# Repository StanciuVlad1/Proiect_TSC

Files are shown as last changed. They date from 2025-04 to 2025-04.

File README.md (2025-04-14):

## Stanciu Vlad-Mihai
#### 331CC
<br><br>

OpenBook este un proiect open-source care urmărește să aducă lectura digitală mai aproape de oricine, printr-un dispozitiv accesibil și ușor de reprodus. În cadrul acestui start-up, dezvoltăm un eBook Reader minimalist, construit pe platforma ESP32-C6, echipat cu un ecran e-paper de 7.5 inch, baterie Li-Po, încărcare prin USB-C și butoane fizice pentru navigare.

Dispozitivul este conceput să fie eficient din punct de vedere energetic și intuitiv în utilizare, oferind o interfață simplă bazată pe GPIO, optimizată pentru afișarea de texte și o experiență de e-reading plăcută.

## Cuprins

- [Prezentare Proiect](#prezentare-proiect)
- [Diagramă Bloc](#diagrama-bloc)
- [Lista de Materiale (BOM)](#lista-de-materiale-bom)
- [Funcționalitate Hardware](#functionalitate-hardware)
- [Alocarea Pinilor ESP32-C6](#alocarea-pinilor-esp32-c6)
- [Note de Design](#note-de-design)

## Prezentare Proiect

OpenBook este un cititor de e-bookuri open-source bazat pe microcontrolerul ESP32-C6. Dispozitivul include un display e-paper, stocare pe card SD pentru e-bookuri, o interfață USB-C pentru alimentare și date, și un design compact care se potrivește într-o carcasă personalizată. Scopul este crearea unui e-reader ieftin, modificabil, care poate fi produs în masă, respectând principiile open-source.

Acest repository conține:

- **Hardware**: Fișiere pentru schemă electrică și PCB.
- **Manufacturing**: Fișiere Gerber, Lista de Materiale (BOM) și fișiere Pick and Place.
- **Mechanical**: Modele 3D ale dispozitivului complet (PCB, baterie, display și carcasă).
- **Images**: Randări ale PCB-ului și dispozitivului.

## 🗂️ Diagrama bloc



## Lista de Materiale (BOM)

Tabelul următor listează componentele folosite în designul OpenBook, cu link-uri către furnizori și datasheet-uri.

| Componentă | Număr Piesă | Cantitate | Link Furnizor | Link Datasheet | Note |
|---|---|---|---|---|---|
| Senzor mediu | BME680 | 1 | [SnapEDA](https://www.snapeda.com/parts/BME680/Bosch/view-part/?welcome=home) | [Bosch](https://www.bosch-sensortec.com/media/boschsensortec/downloads/datasheets/bst-bme680-ds001.pdf) | Senzor temperatură, umiditate |
| Buton tactil | EVQPUJ02K | 3 | [Panasonic](https://industry.panasonic.com/global/en/products/control/switch/light-touch/number/evqpuj02k) | [LCSC](https://www.lcsc.com/datasheet/lcsc_datasheet_2201121800_PANASONIC-EVQPUJ02K_C2936858.pdf) | Butoane navigare și pornire |
| Condensator | R0402 100K | [TBD] | [ComponentSearch](https://componentsearchengine.com/part-view/R0402%201%25%20100%20K%20(RC0402FR-07100KL)/YAGEO) | [Resistor](https://www.resistor.com/assets/pdf/0402tstd.pdf) | Condensator decuplare, SMD 0402 |
| Rezistor | R0402 100K | [TBD] | [ComponentSearch](https://componentsearchengine.com/part-view/R0402%201%25%20100%20K%20(RC0402FR-07100KL)/YAGEO) | [Resistor](https://www.resistor.com/assets/pdf/0402tstd.pdf) | Rezistor, SMD 0402 |
| Baterie | CPH3225A | 1 | [SnapEDA](https://www.snapeda.com/parts/CPH3225A/Seiko+Instruments/view-part/?ref=eda) | [Octopart](https://octopart.com/datasheet/cph3225a-seiko-25340571) | Baterie Li-Po, ~500mAh |
| LED | KP-1608SURCK | 1 | [SnapEDA](https://www.snapeda.com/parts/KP-1608SURCK/Kingbright/view-part/?ref=search&t=LED%200603) | [ELV](https://media.elv.com/file/107153_led_surck1608_data.pdf) | LED 0603, indicator |
| Protecție ESD | USBLC6-2SC6Y | 1 | [SnapEDA](https://www.snapeda.com/parts/USBLC6-2SC6Y/STMicroelectronics/view-part/?ref=eda) | [DigiKey](https://www.digikey.com/en/htmldatasheets/production/1375342/0/0/1/usblc6-2sc6y) | Protecție USB |
| Diodă Schottky | SD0805S020S1R0 | 1 | [Mouser](https://ro.mouser.com/ProductDetail/KYOCERA-AVX/SD0805S020S1R0?qs=jCA%252BPfw4LHbpkAoSnwrdjw%3D%3D) | [AllDataSheet](https://www.alldatasheet.com/view.jsp?Searchword=SD0805S&sField=2) | Diodă pentru alimentare |
| Supresor ESD | PGB1010603MR | 1 | [SnapEDA](https://www.snapeda.com/parts/PGB1010603MR/Littelfuse/view-part/?ref=eda) | [AllDataSheet](https://www.alldatasheet.com/view.jsp?Searchword=Pgb1010603mr) | Protecție ESD |
| Detector tensiune | BD5229G-TR | 1 | [ComponentSearch](https://componentsearchengine.com/part-view/BD5229G-TR/ROHM%20Semiconductor) | [LCSC](https://www.lcsc.com/datasheet/lcsc_datasheet_2201131330_ROHM-Semicon-BD5229G-TR_C962636.pdf) | Monitorizare tensiune |
| Regulator tensiune | XC6220A331MR-G | 1 | [ComponentSearch](https://componentsearchengine.com/part-view/XC6220A331MR-G/Torex) | [AllDataSheet](https://www.alldatasheet.com/view.jsp?Searchword=Xc6220) | Regulator 3.3V |
| Conector USB-C | USB4110-GF-A | 1 | [ComponentSearch](https://componentsearchengine.com/part-view/USB4110-GF-A/GCT%20(GLOBAL%20CONNECTOR%20TECHNOLOGY)) | [GCT](https://gct.co/files/drawings/usb4110.pdf) | Interfață USB-C |
| LED | LEDCHIP-LED0603 | 1 | [Mouser](https://eu.mouser.com/ProductDetail/Adafruit/4208?qs=PzGy0jfpSMtbScLbr0L5dw%3D%3D) | [Arrow](https://www.arrow.com/en/manufacturers/adafruit-industries/datasheets) | LED 0603, Adafruit |
| Bobină | [TBD] | 1 | [Comet](https://store.comet.srl.ro/Catalogue/Product/43497/) | [Scribd](https://www.scribd.com/document/814581278/Datasheet-Bobina) | Inductor pentru alimentare |
| Siguranță resetabilă | PFMF | 1 | [Mouser](https://www.mouser.co.uk/ProductDetail/EPCOS-TDK/B72520T0350K062?qs=dEfas%2FXlABIszF52uu7vrg%3D%3D) | [Mouser](https://ro.mouser.com/c/ds/circuit-protection/thermistors/resettable-fuses-pptc/?m=Schurter&series=PFMF) | Protecție circuit |
| MOSFET | DMG2305UX-7 | 1 | [ComponentSearch](https://componentsearchengine.com/part-view/DMG2305UX-7/Diodes%20Incorporated) | [Mouser](https://www.mouser.com/datasheet/2/115/DMG2305UX-266242.pdf) | Comutare putere |
| MOSFET | Si1308EDL-T1-GE3 | 1 | [ComponentSearch](https://componentsearchengine.com/part-view/SI1308EDL-T1-GE3/Vishay) | [AllDataSheet](https://www.alldatasheet.com/view.jsp?Searchword=Si1308edl) | Comutare putere |
| IC management baterie | MCP73831T-5ACI/OT | 1 | [Mouser](https://www.mouser.co.uk/ProductDetail/Microchip-Technology/MCP73831T-5ACI-OT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) | [Microchip](https://ww1.microchip.com/downloads/en/DeviceDoc/MCP73831-Family-Data-Sheet-DS20001984H.pdf) | Încărcare baterie |
| Lipire SMD | SMD Solder | [TBD] | [GrabCAD](https://grabcad.com/library/solder-jumpers-1) | - | Pentru asamblare SMD |
| Memorie flash | W25Q512JVEIQ | 1 | [SnapEDA](https://www.snapeda.com/parts/W25Q512JVEIQ/Winbond+Electronics/view-part/) | [Mouser](https://www.mouser.com/datasheet/2/949/W25Q512JV_SPI_RevB_06252019_KMS-2487502.pdf) | Memorie SPI |
| Modul microcontroler | ESP32-C6-WROOM-1-N8 | 1 | [SnapEDA](https://www.snapeda.com/parts/ESP32-C6-WROOM-1-N8/Espressif+Systems/view-part/?ref=eda) | [Mouser](https://www.mouser.com/catalog/specsheets/Espressif_ESP32_C6_WROOM_1%20_Datasheet_V0.1_PRELIMINARY_en.pdf) | Modul Wi-Fi/Bluetooth |
| Ceas timp real | DS3231SN# | 1 | [SnapEDA](https://www.snapeda.com/parts/DS3231SN%23/Analog+Devices/view-part/?ref=eda) | [AllDataSheet](https://www.alldatasheet.com/view.jsp?Searchword=Ds3231sn%20datasheet) | RTC pentru timp |
| Monitor baterie | MAX17048G+T10 | 1 | [SnapEDA](https://www.snapeda.com/parts/MAX17048G+T10/Analog+Devices/view-part/?ref=eda) | [AllDataSheet](https://www.alldatasheet.com/view.jsp?Searchword=Max17048) | Monitorizare nivel baterie |

## Funcționalitate Hardware

Hardware-ul OpenBook este proiectat pentru a echilibra costul, eficiența energetică și funcționalitatea. Caracteristicile principale includ:

- **Microcontroler ESP32-C6**:
  - **Nucleu**: Procesor RISC-V single-core.
  - **Conectivitate**: Wi-Fi 6 și Bluetooth 5 pentru actualizări de firmware sau integrare cloud.
  - **Interfețe**: SPI pentru display și card SD, GPIO pentru butoane, USB pentru alimentare și depanare.
  - **Consum de energie**: Optimizat pentru funcționare cu consum redus, cu moduri de sleep pentru a prelungi durata bateriei.

- **Display E-Paper**:
  - Display e-paper de 2.13" (rezoluție [TBD, ex. 250x122 pixeli]).
  - Conectat prin SPI pentru actualizare rapidă și consum redus.
  - Ideal pentru citit în diverse condiții de iluminare, cu consum minim.

- **Modul Card SD**:
  - Stochează e-bookuri și alte fișiere media.
  - Conectat prin SPI pentru transfer de date fiabil.
  - Suportă carduri microSD standard.

- **Interfață USB-C**:
  - Furnizează alimentare (intrare 5V) și încarcă bateria prin IC-ul de management al puterii.
  - Suportă transfer de date pentru depanare sau actualizări de firmware.

- **Baterie și Management Putere**:
  - Baterie Li-Po de 3.7V (~500mAh, capacitate exactă [TBD]).
  - IC de management al puterii (ex. TP4056) gestionează încărcarea și reglarea tensiunii (3.3V pentru ESP32 și alte componente).
  - Durata estimată a bateriei: [TBD, ex. 20 ore de citire activă], bazată pe calcule pentru actualizarea display-ului, modurile sleep ale ESP32 și accesul la cardul SD.

- **Butoane**:
  - Trei butoane tactile pentru navigare (următoarea/pagina anterioară) și pornire/meniu.
  - Conectate la pinii GPIO ai ESP32 cu rezistoare pull-up.

- **Calcule Consum Energie**:
  - ESP32-C6 (activ): ~100mA la 3.3V.
  - Display E-Paper (actualizare): ~10mA pentru 1s per pagină.
  - Card SD (citire): ~50mA în timpul accesului.
  - Consum total activ: [TBD, ex. ~150mA mediu].
  - Mod sleep: [TBD, ex. <1mA].

*(Notă: Actualizează consumul de energie și alte specificații pe baza alegerilor tale de design și a datasheet-urilor.)*

## Alocarea Pinilor ESP32-C6

Pinii ESP32-C6 sunt alocați astfel:

| Pin | Funcție | Componentă/Modul | Note |
|---|---|---|---|
| GPIO0 | SPI MOSI | Display E-Paper, Card SD| Bus SPI comun |
| GPIO1 | SPI MISO | Display E-Paper, Card SD| Bus SPI comun |
| GPIO2 | SPI SCK | Display E-Paper, Card SD| Bus SPI comun |
| GPIO3 | SPI CS (Display) | Display E-Paper | Selectare cip pentru display |
| GPIO4 | SPI CS (Card SD) | Modul Card SD | Selectare cip pentru card SD |
| GPIO5 | Buton 1 (Pagina Urm.) | Buton Tactil | Pull-up, activ low |
| GPIO6 | Buton 2 (Pagina Ant.) | Buton Tactil | Pull-up, activ low |
| GPIO7 | Buton 3 (Pornire/Meniu) | Buton Tactil | Pull-up, activ low |
| GPIO8 | Reset Display | Display E-Paper | Activ low |
| GPIO9 | Busy Display | Display E-Paper | Intrare de la display |
| VBUS | Alimentare USB | Conector USB-C | Intrare 5V |
| 3V3 | Linie Alimentare | Toate componentele | Reglat din baterie/USB |

*(Notă: Verifică alocarea pinilor față de schemă. Actualizează tabelul cu numerele exacte ale pinilor și funcțiile pe baza designului tău.)*

### De ce acești pini?

- **Pini SPI (GPIO0-4)**: Aleși pentru suportul hardware dedicat SPI, asigurând comunicație rapidă și fiabilă cu display-ul și cardul SD. Un bus SPI comun minimizează utilizarea pinilor.
- **Pini Butoane (GPIO5-7)**: Selectați pentru capabilitățile de intrare generală și suport pentru întreruperi, permițând interacțiune rapidă cu utilizatorul.
- **Pini Control Display (GPIO8-9)**: Folosiți pentru semnalele de reset și busy, conform cerințelor datasheet-ului display-ului e-paper.
- **Pini Alimentare (VBUS, 3V3)**: Standard pentru livrarea și reglarea energiei.

## Note de Design

- **Schemă și Design PCB**:
  - Schema (`Hardware/openbook.sch`) respectă referința furnizată.
  - Layout-ul PCB (`Hardware/openbook.brd`) respectă constrângerile mecanice, cu toate componentele pe stratul TOP și rutarea pe ambele straturi TOP și BOTTOM.
  - Traseele de alimentare folosesc lățimea de 0.3mm, iar traseele de semnal au lățimea minimă de 0.15mm, conform ghidului.
  - Antena ESP32-C6 este poziționată la marginea PCB-ului, cu o decupare dedesubt pentru a minimiza interferențele.

- **Design Mecanic**:
  - Modelul 3D (`Mechanical/openbook.step`) include PCB-ul, bateria, display-ul e-paper și carcasa modificată.
  - Bateria se conectează direct la pad-uri de test (fără conector JST) pentru a economisi spațiu.

## 🔧 Provocări și decizii tehnice

- **Erori DRC**  
  Au fost ignorate erorile de tip *"Only INPUT pins on NET ID"* și cele legate de dimensiunile butoanelor și conectorului USB, în conformitate cu ghidul de proiectare, deoarece nu afectează funcționarea corectă a dispozitivului.

- **Amplasarea componentelor**  
  Componentele au fost plasate strategic în jurul ESP32 și al driverului e-paper pentru a reduce lungimea traseelor și a asigura o bună integritate a semnalului.

- **Via Stitching**  
  A fost implementat între planele de masă TOP și BOTTOM, în special în proximitatea ESP32, pentru a îmbunătăți performanța EMI și stabilitatea generală.

- **Silkscreen**  
  Au fost incluse doar denumirile componentelor, fără valorile acestora, pentru a păstra lizibilitatea și a respecta bunele practici în designul PCB-urilor.

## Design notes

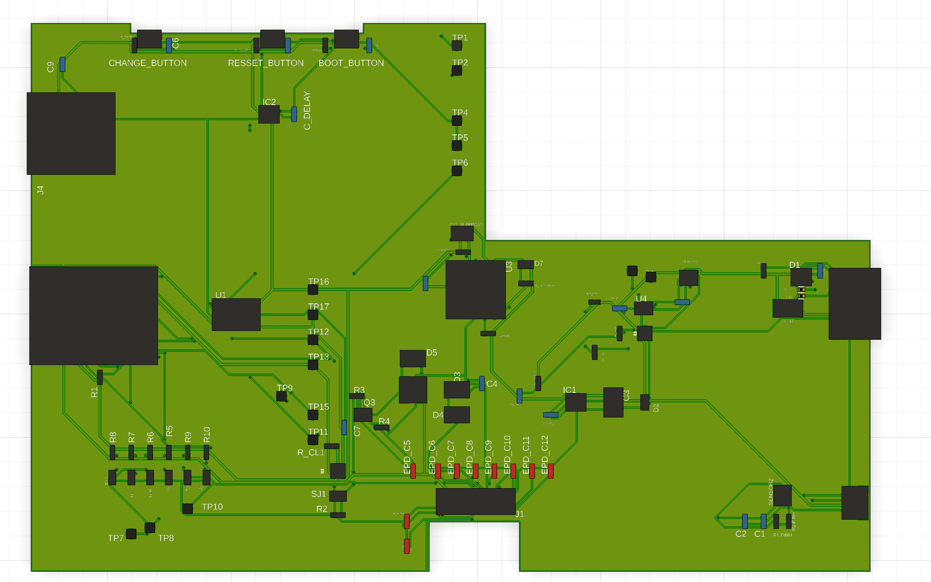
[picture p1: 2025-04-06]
Images/Placa.png

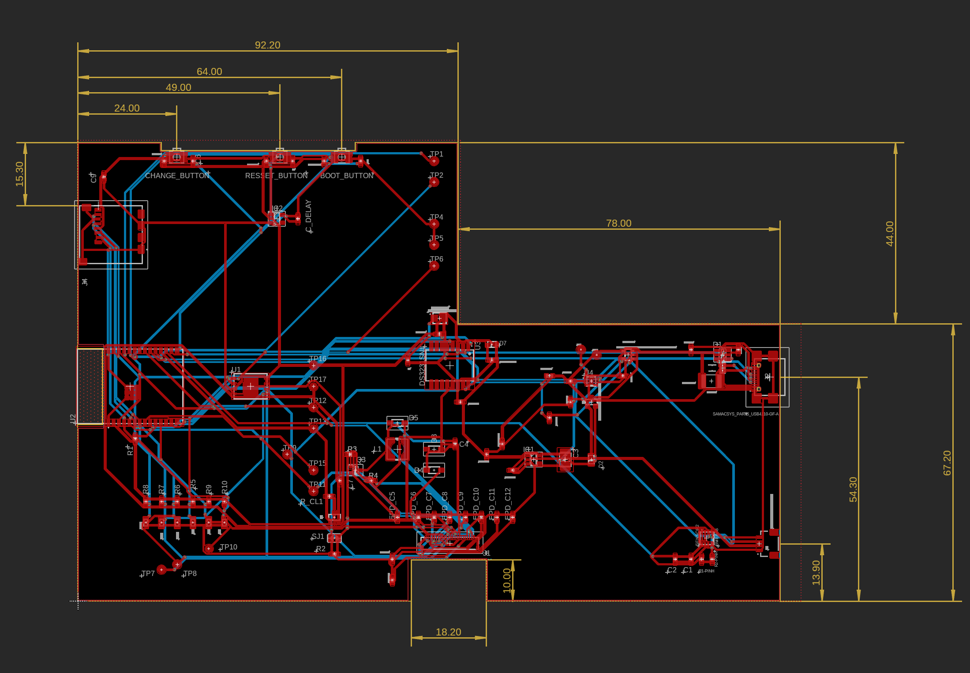
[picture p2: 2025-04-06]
Images/PCB.png

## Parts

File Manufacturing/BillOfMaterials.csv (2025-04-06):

Qty | Value | Device | Package | Parts | Description | ARROW_PART_NUMBER | ARROW_PRICE-STOCK | AVAILABILITY | CATEGORY | CENTROID_NOT_SPECIFIED | CHECK_PRICES | COPYRIGHT | DATASHEET | DESCRIPTION | DIGIKEY_DESCRIPTION | DIGIKEY_PART_NUMBER | HEIGHT | LEAD_FREE | MANUFACTURER | MANUFACTURER_NAME | MANUFACTURER_PART_NUMBER | MF | MFR_NAME | MOUSER_PART_NUMBER | MOUSER_PRICE-STOCK | MOUSER_TESTING_PART_NUMBER | MOUSER_TESTING_PRICE-STOCK | MP | MPN | OPERATING_TEMP | PACKAGE | PART_STATUS | POPULARITY | PREFIX | PRICE | PROD_ID | PURCHASE-URL | RATING | ROHS | ROHS_COMPLIANT | SERIES | SNAPEDA_LINK | SPICEMODEL | SPICEPREFIX | SUB-CATEGORY | TEMPERATURE_RANGE_HIGH | TEMPERATURE_RANGE_LOW | THERMALLOSS | TOLERANCE | TP_SIGNAL_NAME | TYPE | VALUE
1 |  | ADAFRUIT_LEDCHIP-LED0603 | ADAFRUIT_CHIP-LED0603 | CHG_LED | LED
1 |  | SJ | SJ | SJ1 | SMD solder JUMPER |  |  |  |  |  |  |  |  |  |  |  |  |  |  |  |  |  |  |  |  |  |  |  |  |  |  |  | 3
1 | 0.47 | ESP32_WROVER_EAGLE-LTSPICE_RR0402 | ESP32_WROVER_EAGLE-LTSPICE_R0402 | R3 | RESISTOR, European symbol |  |  |  |  |  |  |  |  |  |  |  |  |  |  |  |  |  |  |  |  |  |  |  |  |  |  |  |  |  |  |  |  |  |  |  |  |  | NONE | R
1 | 100K | ESP32_WROVER_EAGLE-LTSPICE_RR0402 | ESP32_WROVER_EAGLE-LTSPICE_R0402 | R1_PWUSB | RESISTOR, European symbol |  |  |  |  |  |  |  |  |  |  |  |  |  |  |  |  |  |  |  |  |  |  |  |  |  |  |  |  |  |  |  |  |  |  |  |  |  | NONE | R
8 | 100nF | EAGLE-LTSPICE_CC0402 | EAGLE-LTSPICE_C0402 | C1, C2, C4_USB, C6, C8, C9, C10, C_DELAY | CAPACITOR, European symbol |  |  |  |  |  |  |  |  |  |  |  |  |  |  |  |  |  |  |  |  |  |  |  |  |  |  |  |  |  |  |  |  |  |  |  |  |  | NONE | C
1 | 100uF | RCL_CPOL-EUCT3528 | RCL_CT3528 | C3 | POLARIZED CAPACITOR, European symbol |  |  |  |  |  |  |  |  |  |  |  |  |  |  |  |  |  |  |  |  |  |  |  |  |  |  |  | 0 |  |  |  |  |  |  |  |  |  |  | C
16 | 10K | ESP32_WROVER_EAGLE-LTSPICE_RR0402 | ESP32_WROVER_EAGLE-LTSPICE_R0402 | R1, R1-PINH, R1-PINH1, R2-PINH, R2-PINH1, R4, R5, R6, R7, R8, R9, R10, R_BOOT, R_CHANGE, R_CL1, R_RESET | RESISTOR, European symbol |  |  |  |  |  |  |  |  |  |  |  |  |  |  |  |  |  |  |  |  |  |  |  |  |  |  |  |  |  |  |  |  |  |  |  |  |  | NONE | R
1 | 10uF | EAGLE-LTSPICE_CC0402 | EAGLE-LTSPICE_C0402 | C7 | CAPACITOR, European symbol |  |  |  |  |  |  |  |  |  |  |  |  |  |  |  |  |  |  |  |  |  |  |  |  |  |  |  |  |  |  |  |  |  |  |  |  |  | NONE | C
1 | 112A-TAAR-R03_ATTEND | 112A-TAAR-R03_ATTEND | 112ATAARR03ATTEND | J4 | Micro SD Card Socket, Push-Push Type, Top Mount, SMT, H=1.83mm, 10u |  |  |  |  |  |  |  |  | Micro SD Card Socket | Push-Push Type | Top Mount | SMT | H=1.83mm | 10u |  |  | 1.9mm |  |  | ATTEND | 112A-TAAR-R03 ATTEND
1 | 15 | ESP32_WROVER_EAGLE-LTSPICE_RR0402 | ESP32_WROVER_EAGLE-LTSPICE_R0402 | R_CAPACITOR | RESISTOR, European symbol |  |  |  |  |  |  |  |  |  |  |  |  |  |  |  |  |  |  |  |  |  |  |  |  |  |  |  |  |  |  |  |  |  |  |  |  |  | NONE | R
1 | 1uF | EAGLE-LTSPICE_CC0402 | EAGLE-LTSPICE_C0402 | C5 | CAPACITOR, European symbol |  |  |  |  |  |  |  |  |  |  |  |  |  |  |  |  |  |  |  |  |  |  |  |  |  |  |  |  |  |  |  |  |  |  |  |  |  | NONE | C
10 | 1uF/50V | EAGLE-LTSPICE_CC0402 | EAGLE-LTSPICE_C0402 | EPD_C1, EPD_C2, EPD_C5, EPD_C6, EPD_C7, EPD_C8, EPD_C9, EPD_C10, EPD_C11, EPD_C12 | CAPACITOR, European symbol |  |  |  |  |  |  |  |  |  |  |  |  |  |  |  |  |  |  |  |  |  |  |  |  |  |  |  |  |  |  |  |  |  |  |  |  |  | NONE | C
1 | 2.2 | ESP32_WROVER_EAGLE-LTSPICE_RR0402 | ESP32_WROVER_EAGLE-LTSPICE_R0402 | R2 | RESISTOR, European symbol |  |  |  |  |  |  |  |  |  |  |  |  |  |  |  |  |  |  |  |  |  |  |  |  |  |  |  |  |  |  |  |  |  |  |  |  |  | NONE | R
1 | 200 | ESP32_WROVER_EAGLE-LTSPICE_RR0402 | ESP32_WROVER_EAGLE-LTSPICE_R0402 | R1_BAT | RESISTOR, European symbol |  |  |  |  |  |  |  |  |  |  |  |  |  |  |  |  |  |  |  |  |  |  |  |  |  |  |  |  |  |  |  |  |  |  |  |  |  | NONE | R
2 | 20V/4.2A/52mO/1.4W | ESP32_WROVER_SPARKFUN-DISCRETESEMI_MOSFET_PCH-DMG2305UX-7 | ESP32_WROVER_SPARKFUN-DISCRETESEMI_SOT23-3 | Q1, Q2 | P-channel MOSFETs |  |  |  |  |  |  |  |  |  |  |  |  |  |  |  |  |  |  |  |  |  |  |  |  |  |  |  |  |  |  | TRAN-14388 |  |  |  |  |  |  |  |  |  |  |  |  |  |  |  | 20V/4.2A/52mO/1.4W
1 | 2K | ESP32_WROVER_EAGLE-LTSPICE_RR0402 | ESP32_WROVER_EAGLE-LTSPICE_R0402 | R2_BAT | RESISTOR, European symbol |  |  |  |  |  |  |  |  |  |  |  |  |  |  |  |  |  |  |  |  |  |  |  |  |  |  |  |  |  |  |  |  |  |  |  |  |  | NONE | R
5 | 4.7uF | EAGLE-LTSPICE_CC0402 | EAGLE-LTSPICE_C0402 | C1_BAT, C1_BAT1, C1_BAT2, C2_BAT, C5_USB | CAPACITOR, European symbol |  |  |  |  |  |  |  |  |  |  |  |  |  |  |  |  |  |  |  |  |  |  |  |  |  |  |  |  |  |  |  |  |  |  |  |  |  | NONE | C
1 | 4.7uF/25V | EAGLE-LTSPICE_CC0402 | EAGLE-LTSPICE_C0402 | C4 | CAPACITOR, European symbol |  |  |  |  |  |  |  |  |  |  |  |  |  |  |  |  |  |  |  |  |  |  |  |  |  |  |  |  |  |  |  |  |  |  |  |  |  | NONE | C
2 | 5k1 | RESISTOR__CHIP-0402(1005-METRIC) | RESC1005X40 | R2-USB, R2-USB1 | Resistor Fixed - Generic |  |  |  | Resistor |  |  |  |  |  |  |  |  |  |  |  |  |  |  |  |  |  |  |  |  |  |  |  |  |  |  |  |  |  |  |  |  |  |  |  | Fixed
1 | 68Uh | 744043680IND_4828-WE-TPC_WRE | IND_4828-WE-TPC_WRE | L1 |  |  |  |  |  |  |  | Copyright (C) 2024 Ultra Librarian. All rights reserved. |  |  |  |  |  |  |  |  | 744043680 |  | Wurth Electronics
1 | BD5229G-TR | BD5229G-TR | SOT95P280X125-5N | IC2 | Voltage Detector with Adjustable Delay Time: CMOS processes are utilized to develop high precision, low current consumption CMOS reset ICs that allow arbitrary setting of the delay time. The extensive lineup includes both Nch Open Drain and CMOS output types in a wide range of detection voltages (from 2.3V to 6.0V, in 0.1V steps), enabling selection of the ideal solution based on customer requirements. In addition, the entire series is of course both lead-free and RoHS-compliant. |  |  |  |  |  |  |  |  | Voltage Detector with Adjustable Delay Time: CMOS processes are utilized to develop high precision | low current consumption CMOS reset ICs that allow arbitrary setting of the delay time. The extensive lineup includes both Nch Open Drain and CMOS output types in a wide range of detection voltages (from 2.3V to 6.0V | in 0.1V steps) | enabling selection of the ideal solution based on customer requirements. In addition | the entire series is of course both lead-free and RoHS-compliant. |  |  | 1.25mm |  |  | ROHM Semiconductor | BD5229G-TR |  |  | 755-BD5229G-TR | https://www.mouser.co.uk/ProductDetail/ROHM-Semiconductor/BD5229G-TR?qs=4kLU8WoGk0vvnhrrYwdszw%3D%3D
1 | BME688 | ESP32_WROVER_BME680_BME680 | ESP32_WROVER_BME680_PSON80P300X300X100-8N | SENSOR2 | Integrated Environmental Unit |  |  | Unavailable |  |  |  |  |  | Integrated Environmental Unit |  |  |  |  |  |  |  | Bosch Sensortec |  |  |  |  |  | BME680 |  |  | LGA-8 Bosch Tools |  |  |  | None
1 | BOOT_BUTTON | BUTTON_CUSYOMV1 | MYBUTTON | BOOT_BUTTON
1 | CHANGE_BUTTON | BUTTON_CUSYOMV1 | MYBUTTON | CHANGE_BUTTON
1 | CPH3225A | CPH3225A | CAPCP3225X100N | C10_SUPERCAP | Cap 0.011F 3.3V 1210 Flat Check availability |  |  | Not in stock |  |  | https://www.snapeda.com/parts/CPH3225A/Seiko+Instruments/view-part/?ref=eda |  |  | 11 mF (EDLC) Supercapacitor 3.3 V 1210 (3225 Metric) - - |  |  |  |  |  |  |  | Seiko Instruments |  |  |  |  |  | CPH3225A |  |  | 1210 Seiko |  |  |  | None |  | https://www.snapeda.com/api/url_track_click_mouser/?unipart_id=562593&manufacturer=Seiko Instruments&part_name=CPH3225A&search_term=None |  |  |  |  | https://www.snapeda.com/parts/CPH3225A/Seiko+Instruments/view-part/?ref=snap
1 | DS3231SN# | DS3231SN# | SOIC127P1032X265-16N | U3 | Real Time Clock Serial 16-Pin SOIC W T/R Check availability |  |  | In Stock |  |  | https://www.snapeda.com/parts/DS3231SN%23/Analog+Devices/view-part/?ref=eda |  |  | Extremely Accurate I²C-Integrated RTC/TCXO/Crystal |  |  |  |  |  |  |  | Analog Devices |  |  |  |  |  | DS3231SN# |  |  | SOIC-16 Maxim |  |  |  | None |  | https://www.snapeda.com/api/url_track_click_mouser/?unipart_id=99048&manufacturer=Analog Devices&part_name=DS3231SN#&search_term=None |  |  |  |  | https://www.snapeda.com/parts/DS3231SN%23/Analog+Devices/view-part/?ref=snap
1 | ESP32-C6-WROOM-1-N8 | ESP32-C6-WROOM-1-N8 | XCVR_ESP32-C6-WROOM-1-N8 | U2 | Check availability |  |  | In Stock |  |  | https://www.snapeda.com/parts/ESP32-C6-WROOM-1-N8/Espressif+Systems/view-part/?ref=eda |  |  | Multiprotocol Modules ESP32-C6 module | Wi-Fi 6 in 2.4 GHz band | Bluetooth 5 | Zigbee 3.0 and Thread. ESP34-WROOM Compatible - ENGINEERING SAMPLE |  |  |  |  |  |  |  | Espressif Systems |  |  |  |  |  | ESP32-C6-WROOM-1-N8 |  |  | None |  |  |  | None |  |  |  |  |  |  | https://www.snapeda.com/parts/ESP32-C6-WROOM-1-N8/Espressif+Systems/view-part/?ref=snap
2 | ESP32_WROVER_AVX---SD0805S020S1R0_AVX_SD0805S020S1R0_0_0AVX_SD0805S020S1R0_0_0 | ESP32_WROVER_AVX---SD0805S020S1R0_AVX_SD0805S020S1R0_0_0AVX_SD0805S020S1R0_0_0 | ESP32_WROVER_AVX---SD0805S020S1R0_AVX_SD0805S020S1R0_0 | D2, D7 | Schottky Barrier Rectifier Diode |  |  |  |  | No |  |  | http://datasheets.avx.com/schottky.pdf |  | DIODE SCHOTTKY 20V 1A 0805 | 478-7800-1-ND |  | yes |  |  |  | AVX |  | 581-SD0805S020S1R0 |  |  |  |  |  |  | 0805 (2012 metric) |  |  | D |  |  |  |  | yes |  |  |  |  |  |  | +125°C | -55°C
1 | ESP32_WROVER_SPARKFUN-IC-POWER_MCP73831 | ESP32_WROVER_SPARKFUN-IC-POWER_MCP73831 | ESP32_WROVER_SPARKFUN-IC-POWER_SOT23-5 | MCP73831 | MCP73831T Li-Ion, Li-Pol Controller |  |  |  |  |  |  |  |  |  |  |  |  |  |  |  |  |  |  |  |  |  |  |  |  |  |  |  |  |  |  | IC-09995
1 | FH34SRJ-24S-0.5SH_99_ | FH34SRJ-24S-0.5SH_99_ | FH34SRJ24S05SH99 | J1 | (0.50mm) Surface Mount, Right Angle |  |  |  |  |  |  |  |  | 24 Position FFC | FPC Connector Contacts | (0.50mm) Surface Mount | Right Angle |  |  | 1.1mm |  |  | Hirose | FH34SRJ-24S-0.5SH(99) |  |  | 798-FH34SRJ24S05SH99 | https://www.mouser.co.uk/ProductDetail/Hirose-Connector/FH34SRJ-24S-0.5SH99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
1 | MAX17048G+T10 | MAX17048G+T10 | SON50P200X200X80-9N | U4 | Check availability |  |  | In Stock |  |  | https://www.snapeda.com/parts/MAX17048G+T10/Analog+Devices/view-part/?ref=eda |  |  | 3µA 1-Cell/2-Cell Fuel Gauge with ModelGauge |  |  |  |  |  |  |  | Analog Devices |  |  |  |  |  | MAX17048G+T10 |  |  | TDFN-8 Maxim |  |  |  | None |  | https://www.snapeda.com/api/url_track_click_mouser/?unipart_id=329239&manufacturer=Analog Devices&part_name=MAX17048G+T10&search_term=None |  |  |  |  | https://www.snapeda.com/parts/MAX17048G+T10/Analog+Devices/view-part/?ref=snap
3 | MBR0530 | MBR0530 | SOD3716X135N | D3, D4, D5 | ON SEMICONDUCTOR - MBR0530 - DIODE, SCHOTTKY, 0.5A, 30V, SOD-123 |  |  | In Stock |  |  | https://www.snapeda.com/parts/MBR0530/Onsemi/view-part/?ref=eda |  |  | Diode Schottky 30 V 500mA Surface Mount SOD-123 |  |  |  |  |  |  |  | ON Semiconductor |  |  |  |  |  | MBR0530 |  |  | SOD-123-2 ON Semiconductor |  |  |  | None |  | https://www.snapeda.com/api/url_track_click_mouser/?unipart_id=179458&manufacturer=ON Semiconductor&part_name=MBR0530&search_term=None |  |  |  |  | https://www.snapeda.com/parts/MBR0530/Onsemi/view-part/?ref=snap
1 | PFMF.050.1 | ESP32C6_VARISTORCN1812 | ESP32C6_VARISTOR_CT/CN1812 | R1_PMF | VARISTOR |  |  |  |  |  |  |  |  |  |  |  |  |  |  |  |  |  |  |  |  |  |  |  |  |  |  |  | 0
6 | PGB1010603MR | PGB1010603MR | DIOC1608X36N | D6, D8, D9, D10, D11, D12 | Check availability |  |  | In Stock |  |  | https://www.snapeda.com/parts/PGB1010603MR/Littelfuse/view-part/?ref=eda |  |  | 150V (Typ) Clamp - Ipp Tvs Diode Surface Mount 0603 (1608 Metric) |  |  |  |  |  |  |  | Littelfuse Inc. |  |  |  |  |  | PGB1010603MR |  |  | 0603 Littelfuse Inc. |  |  |  | None |  | https://www.snapeda.com/api/url_track_click_mouser/?unipart_id=5659453&manufacturer=Littelfuse Inc.&part_name=PGB1010603MR&search_term=None |  |  |  |  | https://www.snapeda.com/parts/PGB1010603MR/Littelfuse/view-part/?ref=snap
1 | QWIIC_RIGHT_ANGLE | QWIIC_CONNECTORJS-1MM | JST04_1MM_RA | J3 | SparkFun I2C Standard Qwiic Connector |  |  |  |  |  |  |  |  |  |  |  |  |  |  |  |  |  |  |  |  |  |  |  |  |  |  |  |  |  |  | CONN-13694 |  |  |  |  |  |  |  |  |  |  |  |  |  |  |  | QWIIC_RIGHT_ANGLE
1 | RESSET_BUTTON | BUTTON_CUSYOMV1 | MYBUTTON | RESSET_BUTTON
1 | SAMACSYS_PARTS_USB4110-GF-A | SAMACSYS_PARTS_USB4110-GF-A | SAMACSYS_PARTS_USB4110GFA | J2 | CONN USB 2.0 TYPE-C R/A SMT |  |  |  |  |  |  |  |  | CONN USB 2.0 TYPE-C R/A SMT |  |  | 3.26mm |  |  | GCT (GLOBAL CONNECTOR TECHNOLOGY) | USB4110-GF-A |  |  | 640-USB4110-GF-A | https://www.mouser.co.uk/ProductDetail/GCT/USB4110-GF-A?qs=KUoIvG%2F9IlYiZvIXQjyJeA%3D%3D
1 | SI1308EDL-T1-GE3 | SI1308EDL-T1-GE3 | SOT65P210X110-3N | Q3 | MOSFET N-Ch 30V 1.5A TrenchFET SC70 Vishay Si1308EDL-T1-GE3 N-channel MOSFET Transistor, 1.5 A, 30 V, 3-Pin SC-70 |  |  | In Stock |  |  | https://www.snapeda.com/parts/SI1308EDL-T1-GE3/Vishay+Siliconix/view-part/?ref=eda |  |  | Si1308EDL-T1-GE3 N-channel MOSFET Transistor | 1.5 A | 30 V | 3-Pin SC-70 | Siliconix / Vishay SI1308EDL-T1-GE3 |  |  |  |  |  |  |  | Vishay Siliconix |  |  |  |  |  | SI1308EDL-T1-GE3 |  |  | SOT-323 Vishay Semiconductor |  |  |  | None |  | https://www.snapeda.com/api/url_track_click_mouser/?unipart_id=274603&manufacturer=Vishay Siliconix&part_name=SI1308EDL-T1-GE3&search_term=None |  |  |  |  | https://www.snapeda.com/parts/SI1308EDL-T1-GE3/Vishay+Siliconix/view-part/?ref=snap
17 | TPTP20R | TPTP20R | TP20R | TP1, TP2, TP3, TP4, TP5, TP6, TP7, TP8, TP9, TP10, TP11, TP12, TP13, TP14, TP15, TP16, TP17 | Test pad |  |  |  |  |  |  |  |  |  |  |  |  |  |  |  |  |  |  |  |  |  |  |  |  |  |  |  | 2
1 | USBLC6-2SC6Y | USBLC6-2SC6Y | SOT95P280X145-6N | D1 | Low Cap. ESD Protection Auto SOT-23-6 STMicroelectronics USBLC6-2SC6Y, Dual Uni-Directional TVS Diode Array, 6-Pin SOT-23 |  |  | In Stock |  |  | https://www.snapeda.com/parts/USBLC6-2SC6Y/STMicroelectronics/view-part/?ref=eda |  |  | 17V Clamp 5A (8/20µs) Ipp Tvs Diode Surface Mount SOT-23-6 |  |  |  |  |  |  |  | STMicroelectronics |  |  |  |  |  | USBLC6-2SC6Y |  |  | SOT-23-6 STMicroelectronics |  |  |  | None |  |  |  |  |  |  | https://www.snapeda.com/parts/USBLC6-2SC6Y/STMicroelectronics/view-part/?ref=snap
1 | W25Q512JVEIQ | W25Q512JVEIQ | SON127P600X800X80-9N | U1 | Check availability |  |  | In Stock |  |  | https://www.snapeda.com/parts/W25Q512JVEIQ/Winbond+Electronics/view-part/?ref=eda |  |  | FLASH - NOR Memory IC 512Mb (64M x 8) SPI - Quad I/O 133 MHz 8-WSON (8x6) |  |  |  |  |  |  |  | Winbond Electronics |  |  |  |  |  | W25Q512JVEIQ |  |  | Package |  |  |  | None |  |  |  |  |  |  | https://www.snapeda.com/parts/W25Q512JVEIQ/Winbond+Electronics/view-part/?ref=snap
1 | XC6220A331MR-G | XC6220A331MR-G | SOT95P280X120-5N | IC1 | LDO Voltage Regulators |  |  |  |  |  |  |  |  | LDO Voltage Regulators |  |  | 1.2mm |  |  | Torex | XC6220A331MR-G |  |  | 865-XC6220A331MR-G | https://www.mouser.co.uk/ProductDetail/Torex-Semiconductor/XC6220A331MR-G?qs=AsjdqWjXhJ8ZSWznL1J0gg%3D%3D

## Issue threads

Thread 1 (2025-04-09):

README incomplet / lipsă – necesită actualizare conform cerințelor TSC

mariaaliu, 2025-04-09:
## Descriere

Acest repository nu conține un fișier `README.md` complet sau structurat conform cerințelor oficiale ale proiectului TSC 2025.

Conform cerințelor disponibile [aici](https://ocw.cs.pub.ro/courses/tsc/proiect2025), README-ul ar trebui să conțină următoarele:

---

## Cerințe minime pentru `README.md`:

1. **O diagramă bloc** cu toate componentele proiectului și conexiunile dintre ele
2. **BOM** (Bill of Materials) în format tabelar, cu:
   - denumirea componentelor
   - link-uri către locații de achiziție (ex: Mouser, Comet)
   - link către datasheet pentru fiecare
3. **Descriere detaliată a funcționalității hardware**
   - ce module/senzori/componente sunt folosite
   - cum comunică cu ESP32-C6
   - eventual calcule energetice
4. **Lista pinilor ESP32-C6 utilizați**
   - fiecare pin și justificarea utilizării
5. **Alte elemente utile pentru review**
   - imagini randate cu PCB-ul
   - layout 3D
   - mențiuni despre carcasă, design log etc.

---

## Sugestie

Ar fi util ca fișierul `README.md` să fie actualizat sau adăugat cât mai curând pentru a facilita validarea și review-ul proiectului.

Mulțumesc!

StanciuVlad1, 2025-04-14:
Readme-ul a fost creat conform cerintei

Closed 2025-04-14.

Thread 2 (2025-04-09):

Lipsă conexiune GND în schema RTC (VRTC supercapacitor)

mariaaliu, 2025-04-09:
### Descriere:

În schema modulului RTC **DS3231SN**, circuitul pentru supercondensatorul `C10_SUPERCAP` nu este conectat direct la **GND**. Această omisiune poate cauza comportamente instabile în funcția de backup a VRTC.

### Detalii issue:
- **Componentă afectată:** `C10_SUPERCAP`, `C8`
- **Net afectat:** `VRTC`
- **Problema:** Lipsă conexiune GND la borna negativă a condensatorului.
- **Locație schematic:** Linia E, între coloanele 2 și 3

### Imagine de referință:

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

### Sugestie de remediere:
Adăugare conexiune la `GND` pentru borna inferioară a `C8` și/sau `C10_SUPERCAP`, pentru a asigura funcționarea corectă a circuitului VRTC.

---

> Issue creat pentru a urmări o potențială eroare hardware care poate afecta stabilitatea sistemului în regim de alimentare backup.

StanciuVlad1, 2025-04-13:
Aceasta problema a fost corectata conform descrierii.

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

Closed 2025-04-13.

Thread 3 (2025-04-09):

Notare incorectă unitate inductanță în schematic

mariaaliu, 2025-04-09:
**Descriere:**
În cadrul subcircuitului *E-Paper Drive Circuit*, componenta **L1** are o valoare notată incorect: `68Uh`.
Corect ar trebui să fie **68uH** (pentru a semnifica `µH` ).

**Impact:**
Această greșeală poate cauza confuzii la interpretarea valorii componentei și poate duce la selecția greșită în procesul de achiziție.

**Ce trebuie schimbat:**
Actualizarea valorii componentei L1 din `68Uh` în `68uH`.

**Captură relevantă:**

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

StanciuVlad1, 2025-04-13:
Aceasta problema a fost corectata conform descrierii.

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

Closed 2025-04-13.

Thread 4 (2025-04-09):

Planul de masă nu urmează conturul plăcii (board outline)

mariaaliu, 2025-04-09:
### Descriere:
Planul de masă nu este aliniat complet cu marginea plăcii, ceea ce poate cauza probleme de integritate electrică, scutare incompletă și chiar erori la fabricarea PCB-ului (ex. tăierea neuniformă a cuprului).

### Imagine exemplu:
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

### Recomandare:
Verifică dacă:
- Conturul plăcii este corect detectat în layout (board outline setat corect)
- Poligonul planului de masă este tras cu `Pour Over All` sau are restricții de clearance ajustate greșit
- Polygonul a fost refăcut (`Repour`) după modificările la outline

StanciuVlad1, 2025-04-13:
Aceasta problema a fost corectata conform descrierii.

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

Closed 2025-04-13.

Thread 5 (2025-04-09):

Poziționare incorectă a conectorului Qwiic (J3)

mariaaliu, 2025-04-09:
### Descriere:
Conectorul Qwiic (marcat ca `J3`) are o dimensiune de placement greșită pe axa verticală (Y). În captura de ecran atașată, distanța este indicată ca fiind **13.90 mm**, în timp ce poziția corectă, conform documentației și carcasei, ar trebui să fie **19.30 mm**.

### Impact:
- Poziționare incorectă în carcasă sau față de alte componente
- Imposibilitatea conectării la header extern
- Posibil risc mecanic în timpul utilizării

### Recomandări:
- Corectează coordonata Y.
- Verifică alinierea cu restul componentelor mecanice.
- Sau se poate schimba carcasa.

### Imagine:

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

StanciuVlad1, 2025-04-13:
Aceasta problema a fost corectata conform descrierii.

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

Closed 2025-04-13.

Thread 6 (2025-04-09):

Lipsă modele 3D pentru validare mecanică

mariaaliu, 2025-04-09:
### Probleme observate:
- Componentele din PCB nu au modele 3D asociate în layout-ul PCB.
- Ecranul și bateria nu sunt modelate în 3D, ceea ce face imposibilă plasarea lor în carcasă.
- Fără aceste elemente, integrarea mecanică în carcasa finală nu poate fi validată (verificare spațiu, coliziuni etc.).

### Impact:
- Nu se poate realiza randarea completă a dispozitivului.
- Nu se poate verifica dacă PCB-ul se potrivește cu carcasa.
- Există riscul de erori mecanice sau incompatibilitate la printare.

### Recomandări:
- Asociază modelele 3D pentru toate componentele PCB-ului.
- Modelează ecranul și bateria.
- Realizează o verificare de ansamblu cu carcasa.

## Imagine stare curentă:

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

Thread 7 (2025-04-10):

Rutare redundantă pentru GND în prezența planului de masă

mariaaliu, 2025-04-10:
### Probleme observate:
- PCB-ul conține mai multe trasee rulate explicit pentru semnalul GND, deși există deja un plan de masă definit.
- Traseele GND sunt rulate pe stratul top și aparțin clasei de semnal `0 default`.

### Impact:
- **Inutilitate funcțională**: Traseele rulate manual pentru GND sunt redundante, întrucât planul de masă oferă deja o cale cu impedanță redusă.
- **Complicații în validare**: Rutarea separată poate genera confuzii în analiza de semnal, calculul traseului critic sau la simulări.
- **Risc de erori la fabricație sau DRC**: Traseele GND pot să nu se conecteze corect cu planul, mai ales dacă nu sunt plasate corespunzător sau dacă apar goluri în polygon.
- **Practică neconformă cu bunele practici PCB**: Traseele de GND ar trebui, în mod normal, să fie delegate complet planului de masă, cu excepția cazurilor justificate.

### Soluție propusă:
- Eliminarea rutărilor explicite de GND acolo unde planul de masă este prezent și conectat corespunzător.
- Utilizarea exclusivă a polygon-fill-urilor pentru GND, asigurând conectivitatea prin vias corect dimensionate.

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

StanciuVlad1, 2025-04-13:
Problema a fost partial rezolvata, deoarece un wire a ramas in aer.

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

Closed 2025-04-13.

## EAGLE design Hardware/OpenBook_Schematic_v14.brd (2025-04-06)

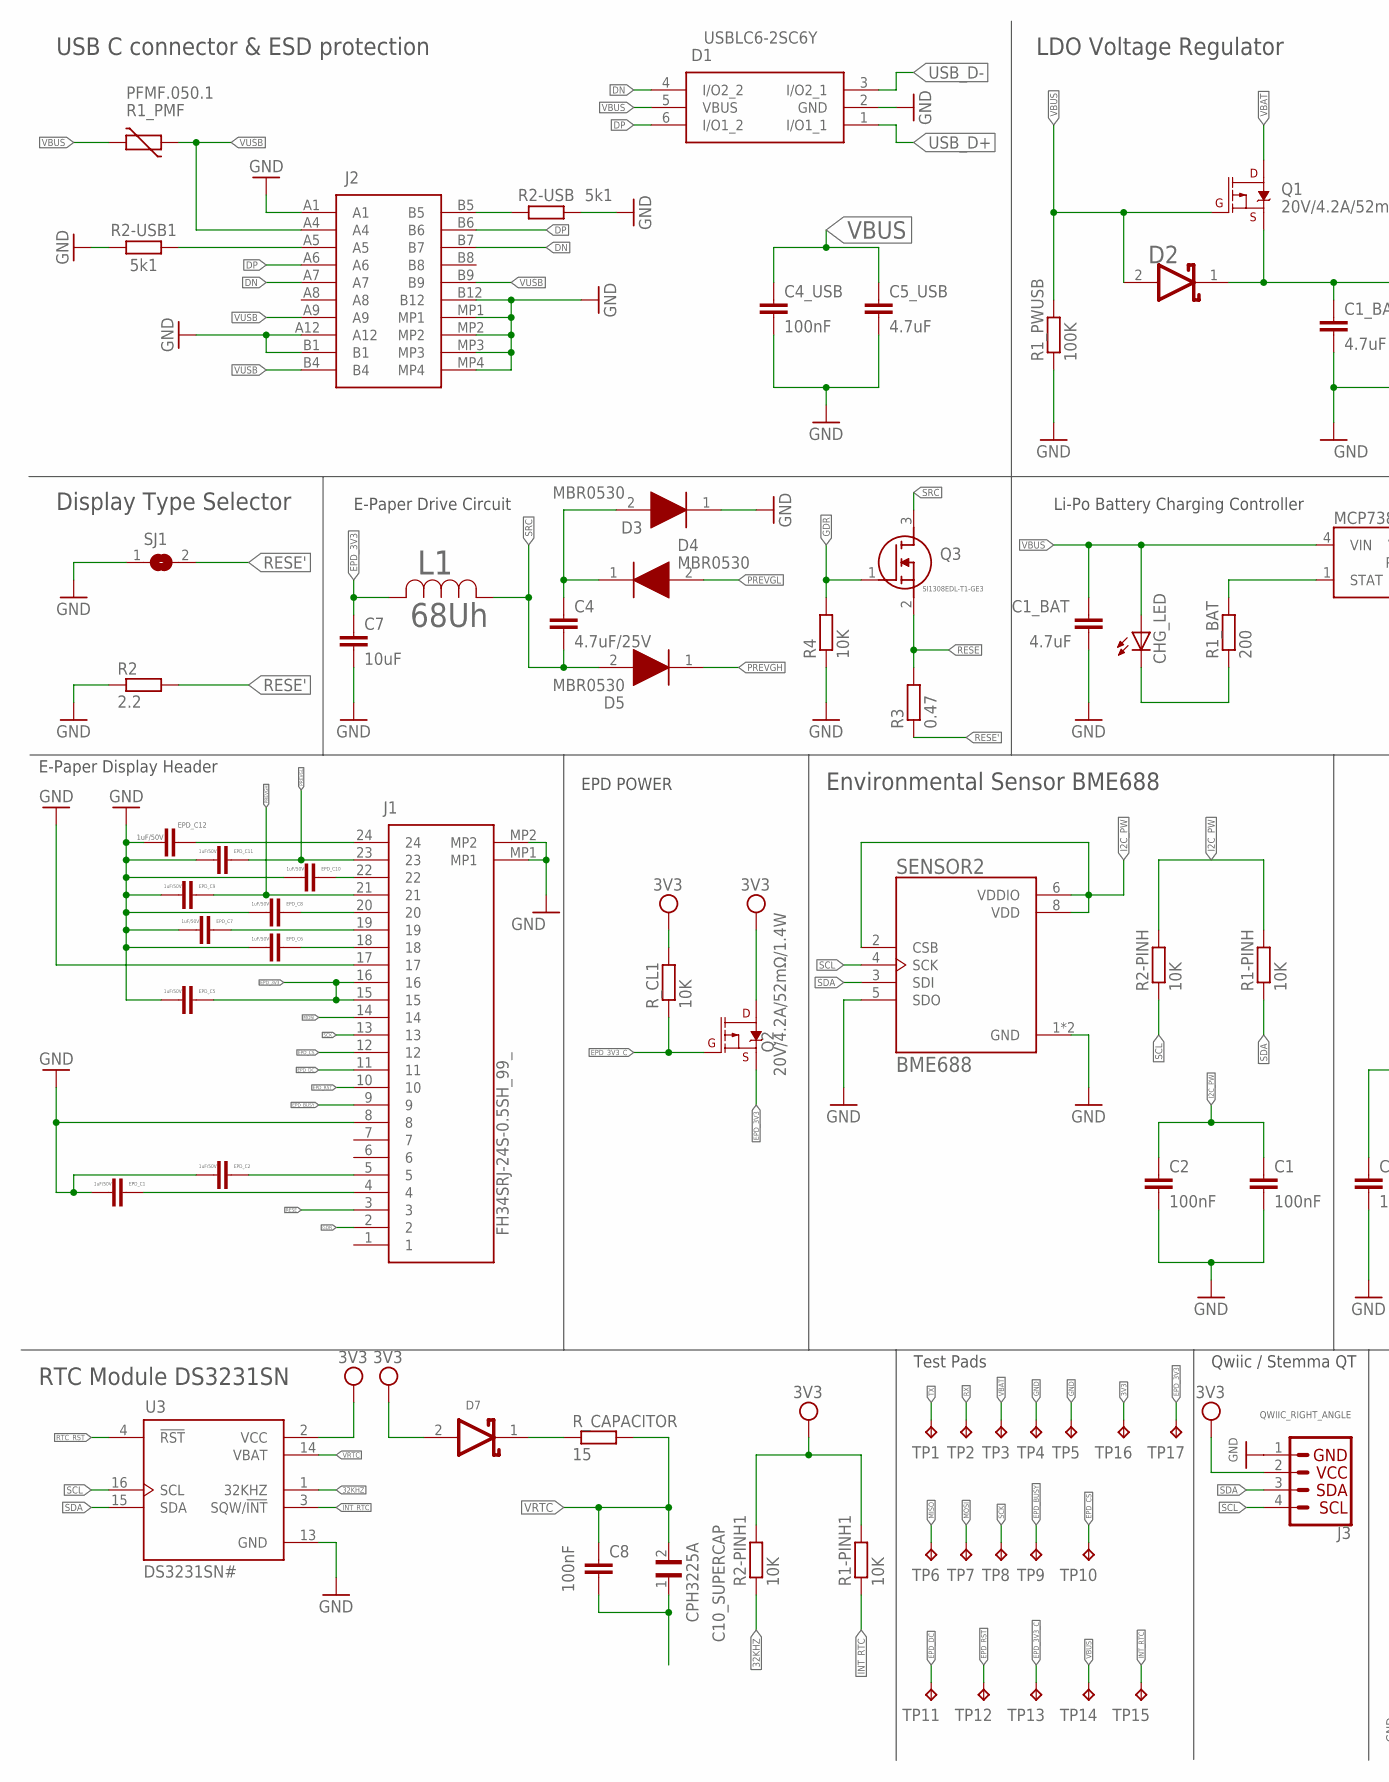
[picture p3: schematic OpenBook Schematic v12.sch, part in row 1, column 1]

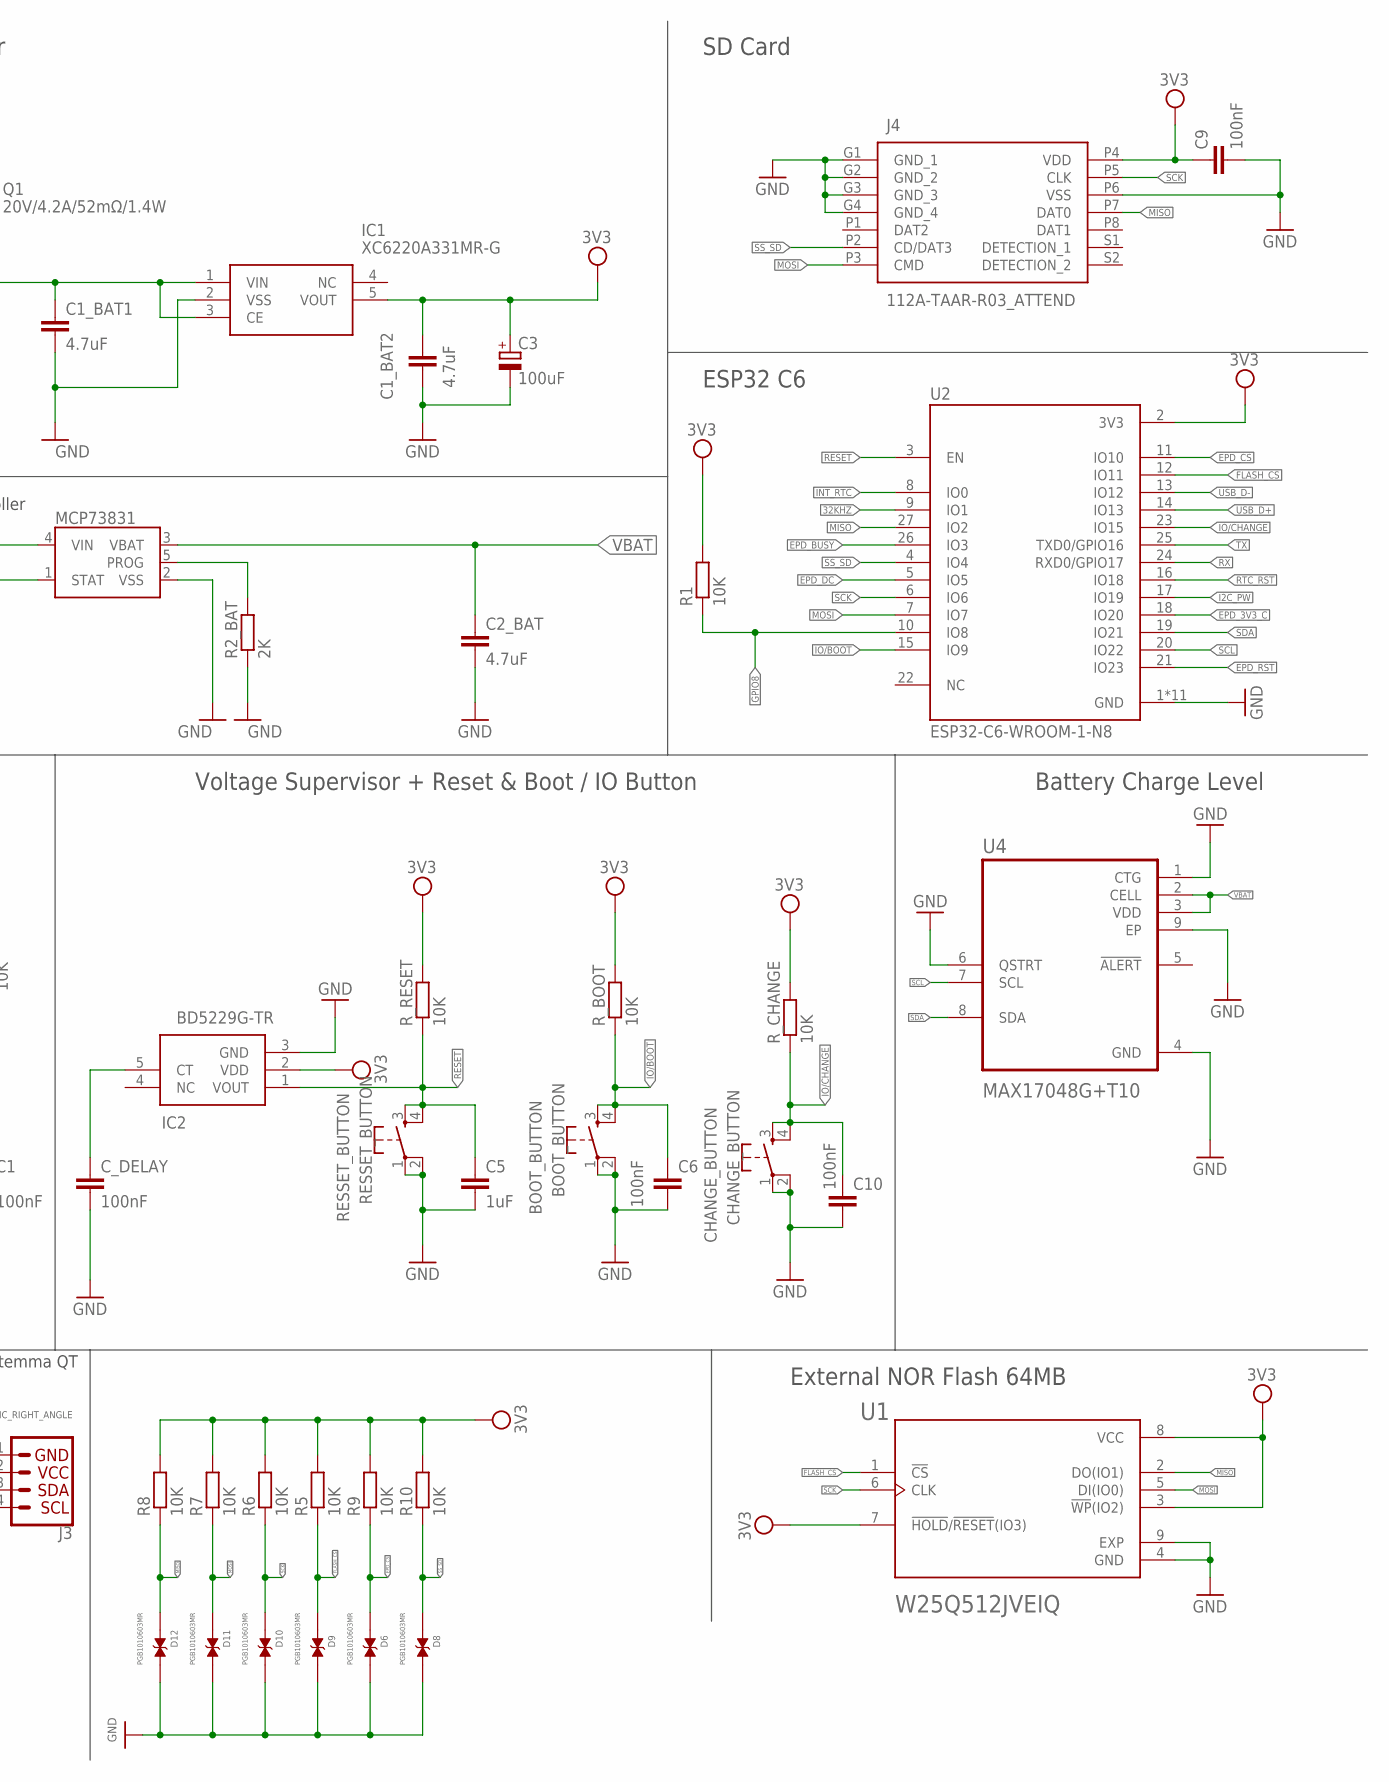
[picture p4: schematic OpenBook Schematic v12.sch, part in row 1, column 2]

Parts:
BOOT_BUTTON: BOOT_BUTTON; MYBUTTON
C1, C2, C4_USB, C6, C8, C9, C10: 100nF; EAGLE-LTSPICE_C0402
C1_BAT, C1_BAT1, C1_BAT2, C2_BAT, C5_USB: 4.7uF; EAGLE-LTSPICE_C0402
C3: 100uF; RCL_CT3528
C4: 4.7uF/25V; EAGLE-LTSPICE_C0402
C5: 1uF; EAGLE-LTSPICE_C0402
C7: 10uF; EAGLE-LTSPICE_C0402
C10_SUPERCAP: CPH3225A; CAPCP3225X100N
CHANGE_BUTTON: CHANGE_BUTTON; MYBUTTON
CHG_LED: ADAFRUIT_LEDCHIP-LED0603; ADAFRUIT_CHIP-LED0603
C_DELAY: 100nF; EAGLE-LTSPICE_C0402
D1: USBLC6-2SC6Y; SOT95P280X145-6N
D2, D7: ESP32_WROVER_AVX---SD0805S020S1R0_AVX_SD0805S020S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; ESP32_WROVER_AVX---SD0805S020S1R0_AVX_SD0805S020S1R0_0
D3, D4, D5: MBR0530; SOD3716X135N
D6, D8, D9, D10, D11, D12: PGB1010603MR; DIOC1608X36N
EPD_C1, EPD_C2, EPD_C5, EPD_C6, EPD_C7, EPD_C8, EPD_C9, EPD_C10, EPD_C11, EPD_C12: 1uF/50V; EAGLE-LTSPICE_C0402
IC1: XC6220A331MR-G; SOT95P280X120-5N
IC2: BD5229G-TR; SOT95P280X125-5N
J1: FH34SRJ-24S-0.5SH_99_; FH34SRJ24S05SH99
J2: SAMACSYS_PARTS_USB4110-GF-A; SAMACSYS_PARTS_USB4110GFA
J3: QWIIC_RIGHT_ANGLE; JST04_1MM_RA
J4: 112A-TAAR-R03_ATTEND; 112ATAARR03ATTEND
L1: 68Uh; IND_4828-WE-TPC_WRE
MCP73831: ESP32_WROVER_SPARKFUN-IC-POWER_MCP73831; ESP32_WROVER_SPARKFUN-IC-POWER_SOT23-5
Q1, Q2: 20V/4.2A/52mΩ/1.4W; ESP32_WROVER_SPARKFUN-DISCRETESEMI_SOT23-3
Q3: SI1308EDL-T1-GE3; SOT65P210X110-3N
R1, R1-PINH, R1-PINH1, R2-PINH, R2-PINH1, R4, R5, R6, R7, R8, R9, R10: 10K; ESP32_WROVER_EAGLE-LTSPICE_R0402
R1_BAT: 200; ESP32_WROVER_EAGLE-LTSPICE_R0402
R1_PMF: PFMF.050.1; ESP32C6_VARISTOR_CT/CN1812
R1_PWUSB: 100K; ESP32_WROVER_EAGLE-LTSPICE_R0402
R2: 2.2; ESP32_WROVER_EAGLE-LTSPICE_R0402
R2-USB, R2-USB1: 5k1; RESC1005X40
R2_BAT: 2K; ESP32_WROVER_EAGLE-LTSPICE_R0402
R3: 0.47; ESP32_WROVER_EAGLE-LTSPICE_R0402
RESSET_BUTTON: RESSET_BUTTON; MYBUTTON
R_BOOT: 10K; ESP32_WROVER_EAGLE-LTSPICE_R0402
R_CAPACITOR: 15; ESP32_WROVER_EAGLE-LTSPICE_R0402
R_CHANGE: 10K; ESP32_WROVER_EAGLE-LTSPICE_R0402
R_CL1: 10K; ESP32_WROVER_EAGLE-LTSPICE_R0402
R_RESET: 10K; ESP32_WROVER_EAGLE-LTSPICE_R0402
SENSOR2: BME688; ESP32_WROVER_BME680_PSON80P300X300X100-8N
SJ1: SJ
TP1, TP2, TP3, TP4, TP5, TP6, TP7, TP8, TP9, TP10, TP11, TP12, TP13, TP14, TP15, TP16, TP17: TPTP20R; TP20R
U1: W25Q512JVEIQ; SON127P600X800X80-9N
U2: ESP32-C6-WROOM-1-N8; XCVR_ESP32-C6-WROOM-1-N8
U3: DS3231SN#; SOIC127P1032X265-16N
U4: MAX17048G+T10; SON50P200X200X80-9N

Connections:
3V3: C1_BAT2.1, C3.+, C9.1, D7.2 (ANODE), IC1.5 (VOUT), IC2.2 (VDD), J3.2, J4.P4 (VDD), Q2.3 (D), R1.2, R1-PINH1.2, R2-PINH1.2, R5.2, R6.2, R7.2, R8.2, R9.2, R10.2, R_BOOT.2, R_CHANGE.2, R_CL1.2, R_RESET.2, TP16.TP, U1.3 (!WP!(IO2)), U1.7 (!HOLD!/!RESET!(IO3)), U1.8 (VCC), U2.2 (3V3), U3.2 (VCC)
32KHZ: R2-PINH1.1, U2.9 (IO1), U3.1 (32KHZ)
DN: D1.4 (I/O2_2), J2.A7, J2.B7
DP: D1.6 (I/O1_2), J2.A6, J2.B6
EPD_3V3: C7.1, EPD_C5.1, J1.15, J1.16, L1.2, Q2.2 (S), TP17.TP
EPD_3V3_C: Q2.1 (G), R_CL1.1, TP13.TP, U2.18 (IO20)
EPD_BUSY: J1.9, TP9.TP, U2.26 (IO3)
EPD_CS: D6.2, J1.12, R9.1, TP10.TP, U2.11 (IO10)
EPD_DC: J1.11, TP11.TP, U2.5 (IO5)
EPD_RST: J1.10, TP12.TP, U2.21 (IO23)
FLASH_CS: D9.2, R5.1, U1.1 (!CS), U2.12 (IO11)
GDR: J1.2, Q3.1 (G), R4.2
GND: BOOT_BUTTON.1, BOOT_BUTTON.2, C1.2, C1_BAT.2, C1_BAT1.2, C1_BAT2.2, C2.2, C2_BAT.2, C3.-, C4_USB.2, C5.2, C5_USB.2, C6.2, C7.2, C9.2, C10.2, CHANGE_BUTTON.1, CHANGE_BUTTON.2, C_DELAY.2, D1.2 (GND), D3.1 (K), D6.1, D8.1, D9.1, D10.1, D11.1, D12.1, EPD_C1.2, EPD_C2.2, EPD_C5.2, EPD_C6.2, EPD_C7.2, EPD_C8.2, EPD_C9.2, EPD_C10.2, EPD_C11.2, EPD_C12.2, IC1.2 (VSS), IC2.3 (GND), J1.8, J1.17, J1.MP1, J1.MP2, J2.A1, J2.A12, J2.B1, J2.B12, J2.MP1, J2.MP2, J2.MP3, J2.MP4, J3.1, J4.G1 (GND_1), J4.G2 (GND_2), J4.G3 (GND_3), J4.G4 (GND_4), J4.P6 (VSS), MCP73831.2 (VSS), R1_PWUSB.1, R2.1, R2-USB.2, R2-USB1.1, R2_BAT.1, R4.1, RESSET_BUTTON.1, RESSET_BUTTON.2, SENSOR2.1 (GND), SENSOR2.5 (SDO), SENSOR2.7 (GND), SJ1.1, TP4.TP, TP5.TP, U1.4 (GND), U1.9 (EXP), U2.1 (GND), U2.28 (GND), U2.29_1 (GND), U2.29_2 (GND), U2.29_3 (GND), U2.29_4 (GND), U2.29_5 (GND), U2.29_6 (GND), U2.29_7 (GND), U2.29_8 (GND), U2.29_9 (GND), U3.13 (GND), U4.1 (CTG), U4.4 (GND), U4.6 (QSTRT), U4.9 (EP)
GPIO8: R1.1, U2.10 (IO8)
I2C_PW: C1.1, C2.1, SENSOR2.2 (CSB), SENSOR2.6 (VDDIO), SENSOR2.8 (VDD), U2.17 (IO19)
INT_RTC: R1-PINH1.1, TP15.TP, U2.8 (IO0), U3.3 (SQW/!INT)
IO/BOOT: BOOT_BUTTON.3, BOOT_BUTTON.4, C6.1, R_BOOT.1, U2.15 (IO9)
IO/CHANGE: C10.1, CHANGE_BUTTON.3, CHANGE_BUTTON.4, R_CHANGE.1, U2.23 (IO15)
MISO: D12.2, J4.P7 (DAT0), R8.1, TP6.TP, U1.2 (DO(IO1)), U2.27 (IO2)
MOSI: D11.2, J1.14, J4.P3 (CMD), R7.1, TP7.TP, U1.5 (DI(IO0)), U2.7 (IO7)
unnamed: C1_BAT1.1, D2.1 (CATHODE), IC1.1 (VIN), IC1.3 (CE), Q1.2 (S)
unnamed: J2.A5, R2-USB1.2
unnamed: J2.B5, R2-USB.1
unnamed: EPD_C12.1, J1.24
unnamed: C4.1, D3.2 (A), D4.1 (K)
unnamed: CHG_LED.C, R1_BAT.1
unnamed: MCP73831.1 (STAT), R1_BAT.2
unnamed: R1-PINH.2, R2-PINH.2
unnamed: MCP73831.5 (PROG), R2_BAT.2
unnamed: C_DELAY.1, IC2.5 (CT)
unnamed: D7.1 (CATHODE), R_CAPACITOR.1
unnamed: C8.2, C10_SUPERCAP.1
unnamed: EPD_C10.1, J1.22
unnamed: EPD_C8.1, J1.20
unnamed: EPD_C7.1, J1.19
unnamed: EPD_C6.1, J1.18
unnamed: EPD_C2.1, J1.5
unnamed: EPD_C1.1, J1.4
PREVGH: D5.1 (K), EPD_C9.1, J1.21
PREVGL: D4.2 (A), EPD_C11.1, J1.23
RESE: J1.3, Q3.2 (S), R3.2
RESE': R2.2, R3.1, SJ1.2
RESET: C5.1, IC2.1 (VOUT), RESSET_BUTTON.3, RESSET_BUTTON.4, R_RESET.1, U2.3 (EN)
RTC_RST: U2.16 (IO18), U3.4 (!RST)
RX: TP2.TP, U2.24 (RXD0/GPIO17)
SCK: D10.2, J1.13, J4.P5 (CLK), R6.1, TP8.TP, U1.6 (CLK), U2.6 (IO6)
SCL: J3.4, R2-PINH.1, SENSOR2.4 (SCK), U2.20 (IO22), U3.16 (SCL), U4.7 (SCL)
SDA: J3.3, R1-PINH.1, SENSOR2.3 (SDI), U2.19 (IO21), U3.15 (SDA), U4.8 (SDA)
SRC: C4.2, D5.2 (A), L1.1, Q3.3 (D)
SS_SD: D8.2, J4.P2 (CD/DAT3), R10.1, U2.4 (IO4)
TX: TP1.TP, U2.25 (TXD0/GPIO16)
USB_D+: D1.1 (I/O1_1), U2.14 (IO13)
USB_D-: D1.3 (I/O2_1), U2.13 (IO12)
VBAT: C2_BAT.1, MCP73831.3 (VBAT), Q1.3 (D), TP3.TP, U4.2 (CELL), U4.3 (VDD)
VBUS: C1_BAT.1, C4_USB.1, C5_USB.1, CHG_LED.A, D1.5 (VBUS), D2.2 (ANODE), MCP73831.4 (VIN), Q1.1 (G), R1_PMF.2, R1_PWUSB.2, TP14.TP
VRTC: C8.1, C10_SUPERCAP.2, R_CAPACITOR.2, U3.14 (VBAT)
VUSB: J2.A4, J2.A9, J2.B4, J2.B9, R1_PMF.1

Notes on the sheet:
USB C connector & ESD protection
SD Card
LDO Voltage Regulator
ESP32 C6
Display Type Selector
E-Paper Drive Circuit
Li-Po Battery Charging Controller
E-Paper Display Header
EPD POWER
Environmental Sensor BME688
Voltage Supervisor + Reset & Boot / IO Button
Battery Charge Level
RTC Module DS3231SN
Test Pads
Qwiic / Stemma QT
External NOR Flash 64MB

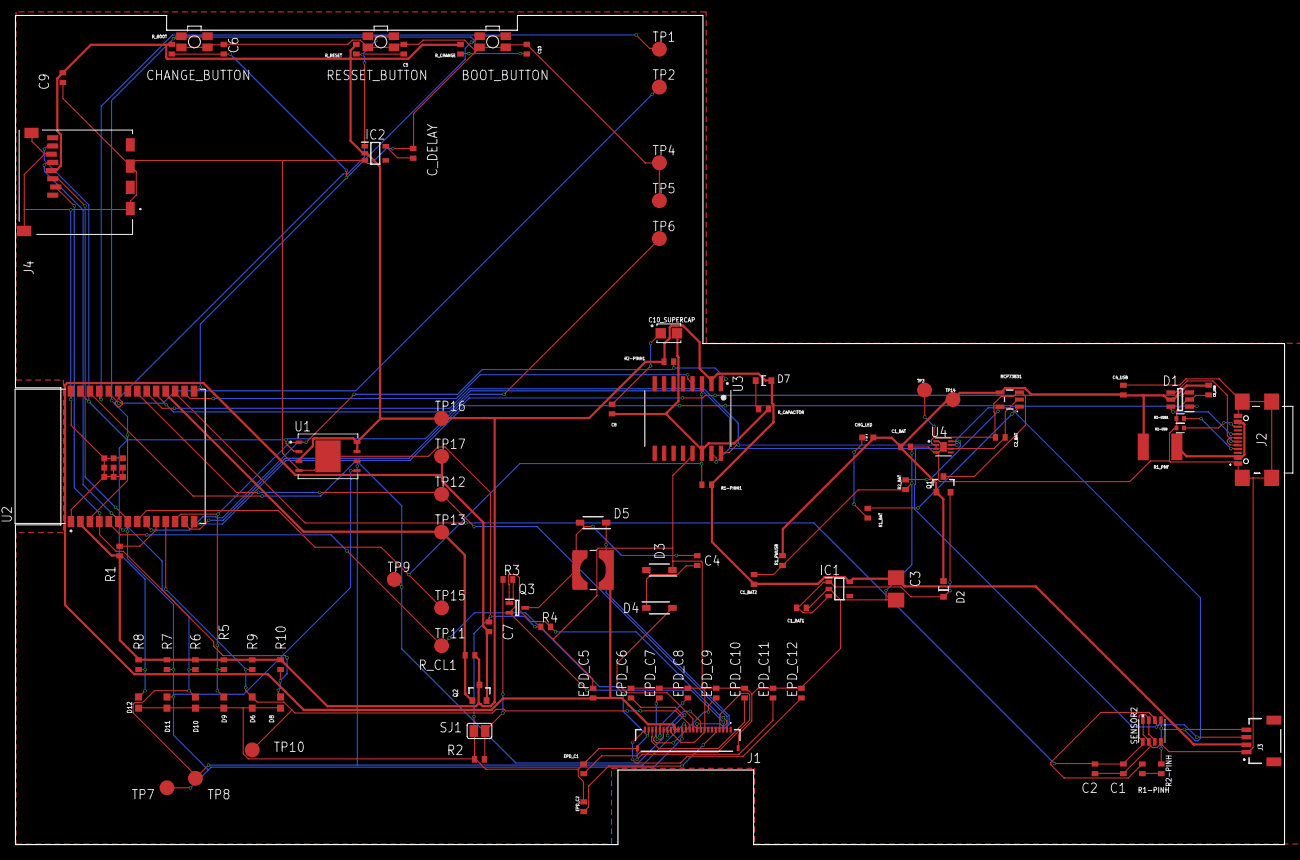
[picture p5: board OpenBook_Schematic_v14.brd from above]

Board: 2 copper layers, 170.2 x 111.2 mm, 103 parts (0 on the bottom side), 57 nets.

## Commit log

2025-04-06 Pushing Mechanical and Hardware
    [OpenBook Schematic v12.sch, OpenBook_Schematic_v14.brd]
2025-04-06 Adding part of manufacturing
    [copper_bottom.gbr, copper_top.gbr, drill_1_16.xln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]
2025-04-06 Removing useless files and adding Bill Of Materials
    [BillOfMaterials.csv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]

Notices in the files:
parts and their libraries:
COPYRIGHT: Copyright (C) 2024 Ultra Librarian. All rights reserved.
